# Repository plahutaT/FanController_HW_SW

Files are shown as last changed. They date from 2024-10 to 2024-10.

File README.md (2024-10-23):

# FanController PCB

A custom PCB for controlling fans in industrial electronic cabinets. It uses the PIC18F45K22 microcontroller and interfaces with two DS18B20 temperature sensors to regulate fan speed based on the temperature difference inside and outside the cabinet. It supports both 230V AC and 24V DC fans and has an option for logging data over TCP via an ESP01 module.

## Features

- Interfaces with two DS18B20 temperature sensors.
- Supports one 230V AC fan and one 24V DC fan.
- Regulates fan speed based on the temperature difference inside and outside the cabinet.
- Optional data logging over TCP using an ESP01 module.

## Hardware Components

- **Microcontroller**: PIC18F45K22
- **Temperature Sensors**: 2x DS18B20
- **Fan Support**:
  - 230V AC fan
  - 24V DC fan
- **Connectivity**: ESP01 module for optional data logging over TCP

### Prerequisites

- **MPLAB X IDE** for firmware development.
- **PICkit** or another compatible programmer for flashing the PIC18F45K22.
- PCB and components (refer to the Bill of Materials in the `/hardware` directory).

## Usage

Once powered on, the FanController PCB will:

- Read temperatures from the inside and outside DS18B20 sensors.
- Automatically adjust the speed of the connected 230V AC or 24V DC fan based on the temperature difference.
- Optionally, log temperature and fan speed data over TCP if the ESP01 module is connected and properly configured.

## License

This project is licensed under the MIT License. See the [LICENSE](LICENSE) file for details.

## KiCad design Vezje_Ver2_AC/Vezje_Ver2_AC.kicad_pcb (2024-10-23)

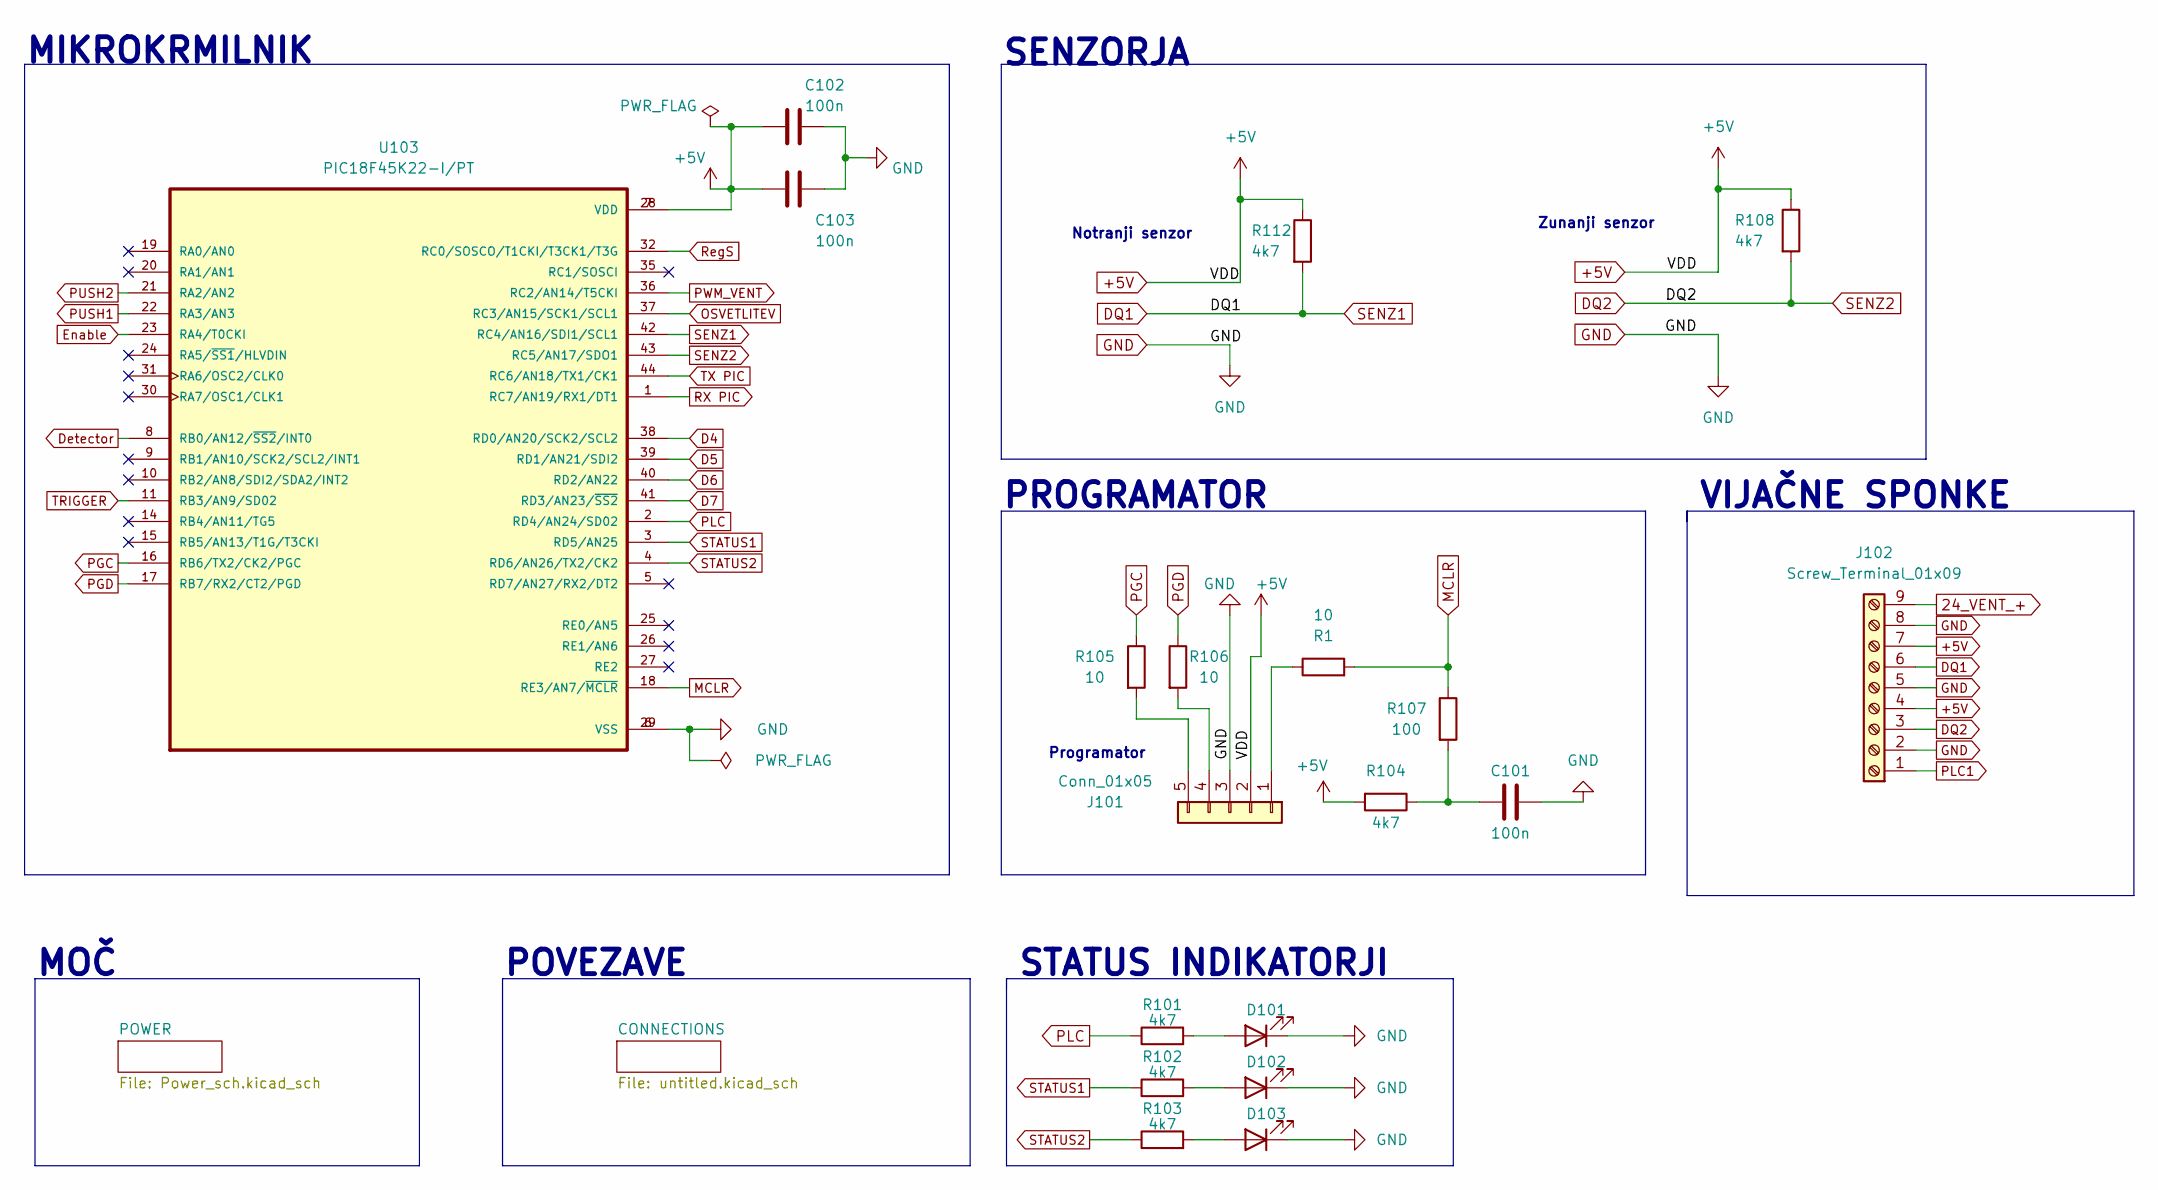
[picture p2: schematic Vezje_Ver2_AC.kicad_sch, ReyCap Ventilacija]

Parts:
C101, C102, C103: 100n; C_1206_3216Metric_Pad1.33x1.80mm_HandSolder
D101, D102, D103: LED; LED_1206_3216Metric_Pad1.42x1.75mm_HandSolder
J101: Conn_01x05; PinHeader_1x05_P2.54mm_Vertical
J102: Screw_Terminal_01x09; TerminalBlock_Phoenix_MKDS-1,5-9-5.08_1x09_P5.08mm_Horizont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
R1, R105, R106: 10; R_1206_3216Metric_Pad1.30x1.75mm_HandSolder
R101, R102, R103, R104, R108, R112: 4k7; R_1206_3216Metric_Pad1.30x1.75mm_HandSolder
R107: 100; R_1206_3216Metric_Pad1.30x1.75mm_HandSolder
U103: PIC18F45K22-I/PT; QFP80P1200X1200X120-44N

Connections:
24_VENT_+: J102.9; also elsewhere on the board
+5V: C102.1, C103.1, J101.2, J102.4, J102.7, R104.2, R108.1, R112.1, U103.7 (VDD), U103.28 (VDD); also elsewhere on the board
D4: U103.38 (RD0/AN20/SCK2/SCL2); also elsewhere on the board
D5: U103.39 (RD1/AN21/SDI2); also elsewhere on the board
D6: U103.40 (RD2/AN22); also elsewhere on the board
D7: U103.41 (RD3/AN23/~SS2); also elsewhere on the board
DQ1: J102.6, R112.2, U103.42 (RC4/AN16/SDI1/SCL1)
DQ2: J102.3, R108.2, U103.43 (RC5/AN17/SDO1)
Detector: U103.8 (RB0/AN12/~SS2/INT0); also elsewhere on the board
Enable: U103.23 (RA4/T0CKI); also elsewhere on the board
GND: C101.2, C102.2, C103.2, D101.1 (K), D102.1 (K), D103.1 (K), J101.3, J102.2, J102.5, J102.8, U103.6 (VSS), U103.29 (VSS); also elsewhere on the board
MCLR: R1.2, R107.1, U103.18 (RE3/AN7/~MCLR)
unnamed: C101.1, R104.1, R107.2
unnamed: D101.2 (A), R101.2
unnamed: D102.2 (A), R102.2
unnamed: D103.2 (A), R103.2
unnamed: J101.1, R1.1
unnamed: J101.4, R106.2
unnamed: J101.5, R105.2
OSVETLITEV: U103.37 (RC3/AN15/SCK1/SCL1); also elsewhere on the board
PGC: R105.1, U103.16 (RB6/TX2/CK2/PGC)
PGD: R106.1, U103.17 (RB7/RX2/CT2/PGD)
PLC: R101.1, U103.2 (RD4/AN24/SD02); also elsewhere on the board
PLC1: J102.1; also elsewhere on the board
PUSH1: U103.22 (RA3/AN3); also elsewhere on the board
PUSH2: U103.21 (RA2/AN2); also elsewhere on the board
PWM_VENT: U103.36 (RC2/AN14/T5CKI); also elsewhere on the board
RX PIC: U103.1 (RC7/AN19/RX1/DT1); also elsewhere on the board
RegS: U103.32 (RC0/SOSCO/T1CKI/T3CK1/T3G); also elsewhere on the board
STATUS1: R102.1, U103.3 (RD5/AN25)
STATUS2: R103.1, U103.4 (RD6/AN26/TX2/CK2)
TRIGGER: U103.11 (RB3/AN9/SD02); also elsewhere on the board
TX PIC: U103.44 (RC6/AN18/TX1/CK1); also elsewhere on the board

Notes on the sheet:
MOČ
Notranji senzor
VIJAČNE SPONKE
PROGRAMATOR
MIKROKRMILNIK
POVEZAVE
Programator
STATUS INDIKATORJI
SENZORJA
Zunanji senzor

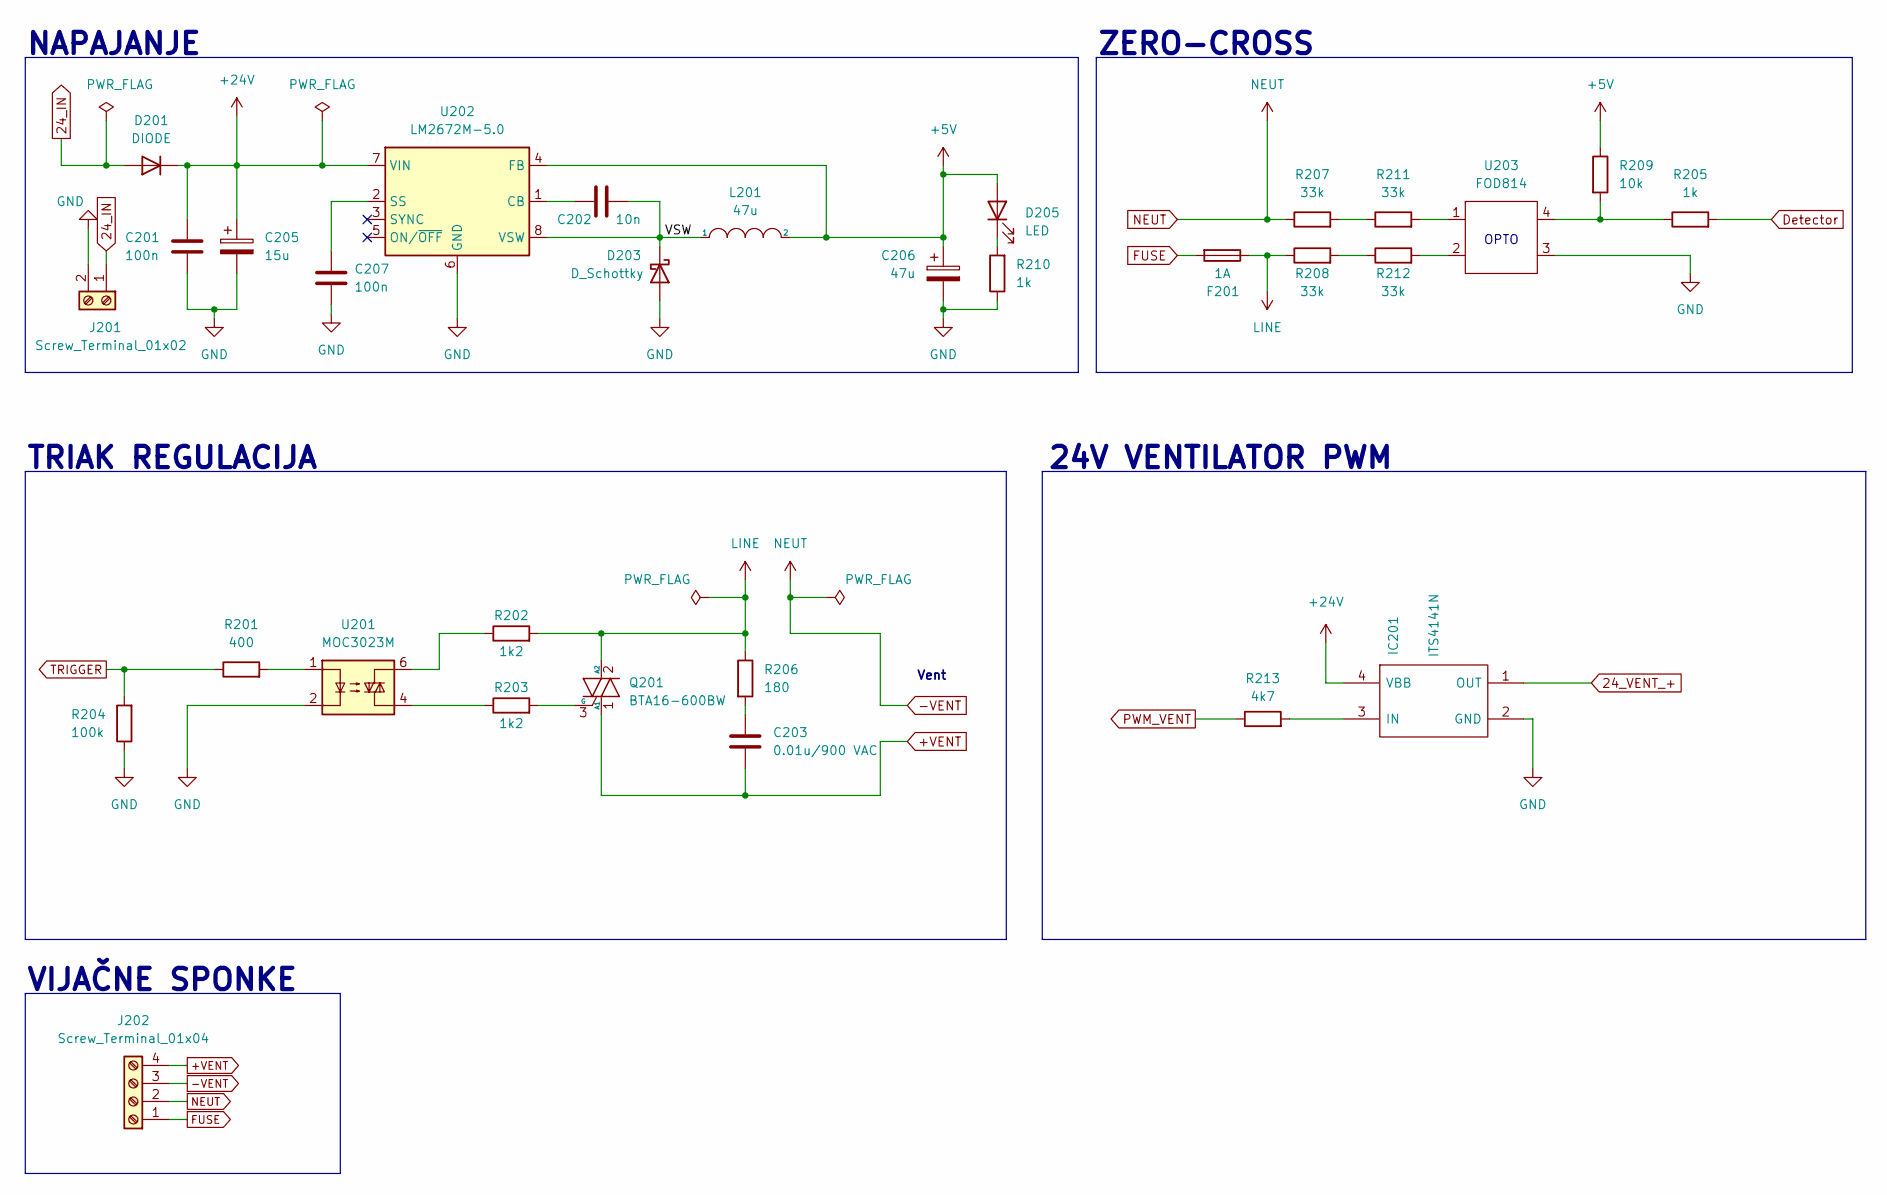
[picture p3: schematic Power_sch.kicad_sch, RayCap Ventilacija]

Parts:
C201, C207: 100n; C_1206_3216Metric_Pad1.33x1.80mm_HandSolder
C202: 10n; C_1206_3216Metric_Pad1.33x1.80mm_HandSolder
C203: 0.01u/900 VAC; C_Rect_L18.0mm_W5.0mm_P15.00mm_FKS3_FKP3
C205: 15u; CP_Elec_8x6.7
C206: 47u; CP_Elec_6.3x9.9
D201: DIODE; D_SMB
D203: D_Schottky; D_SMB
D205: LED; LED_1206_3216Metric_Pad1.42x1.75mm_HandSolder
F201: 1A; 696105003002
IC201: ITS4141N; SOT230P700X170-4N; Manufacturer_Part_Number ITS4141N; Mouser Part Number 726-ITS4141N
J201: Screw_Terminal_01x02; TerminalBlock_Phoenix_MKDS-1,5-2-5.08_1x02_P5.08mm_Horizont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
J202: Screw_Terminal_01x04; TerminalBlock_Phoenix_MKDS-1,5-4-5.08_1x04_P5.08mm_Horizont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
L201: 47u; L_7.3x7.3_H3.5
Q201: BTA16-600BW; TO-220-3_Vertical
R201: 400; R_1206_3216Metric_Pad1.30x1.75mm_HandSolder
R202, R203: 1k2; R_Axial_DIN0207_L6.3mm_D2.5mm_P10.16mm_Horizontal
R204: 100k; R_1206_3216Metric_Pad1.30x1.75mm_HandSolder
R205, R210: 1k; R_1206_3216Metric_Pad1.30x1.75mm_HandSolder
R206: 180; R_Axial_DIN0207_L6.3mm_D2.5mm_P10.16mm_Horizontal
R207, R208, R211, R212: 33k; R_1210_3225Metric_Pad1.30x2.65mm_HandSolder
R209: 10k; R_1206_3216Metric_Pad1.30x1.75mm_HandSolder
R213: 4k7; R_1206_3216Metric_Pad1.30x1.75mm_HandSolder
U201: MOC3023M; DIP-6_W7.62mm
U202: LM2672M-5.0; SOIC-8_3.9x4.9mm_P1.27mm
U203: FOD814; DIP762W50P254L510H440Q4

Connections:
24_IN: D201.2 (K), J201.1
24_VENT_+: IC201.1 (OUT); also elsewhere on the board
+5V: C206.1, D205.2 (A), L201.2, R209.1, U202.4 (FB); also elsewhere on the board
+24V: C201.1, C205.1, D201.1 (A), IC201.4 (VBB), U202.7 (VIN); also elsewhere on the board
+VENT: C203.2, J202.4, Q201.1 (A1)
-VENT: J202.2, J202.3, R207.1
/POWER/VSW: C202.2, D203.1 (K), L201.1, U202.8 (VSW)
Detector: R205.2; also elsewhere on the board
FUSE: F201.2, J202.1
GND: C201.2, C205.2, C206.2, C207.2, D203.2 (A), IC201.2 (GND), J201.2, R204.1, R210.1, U201.2, U202.6 (GND), U203.3; also elsewhere on the board
LINE: F201.1, Q201.2 (A2), R202.2, R206.1, R208.1
unnamed: C202.1, U202.1 (CB)
unnamed: C203.1, R206.2
unnamed: C207.1, U202.2 (SS)
unnamed: D205.1 (K), R210.2
unnamed: IC201.3 (IN), R213.2
unnamed: Q201.3 (G), R203.2
unnamed: R201.2, U201.1
unnamed: R202.1, U201.6
unnamed: R203.1, U201.4
unnamed: R205.1, R209.2, U203.4
unnamed: R207.2, R211.1
unnamed: R208.2, R212.1
unnamed: R211.2, U203.1
unnamed: R212.2, U203.2
PWM_VENT: R213.1; also elsewhere on the board
TRIGGER: R201.1, R204.2; also elsewhere on the board

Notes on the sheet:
24V VENTILATOR PWM
OPTO
NAPAJANJE
VIJAČNE SPONKE
Vent
ZERO-CROSS
TRIAK REGULACIJA

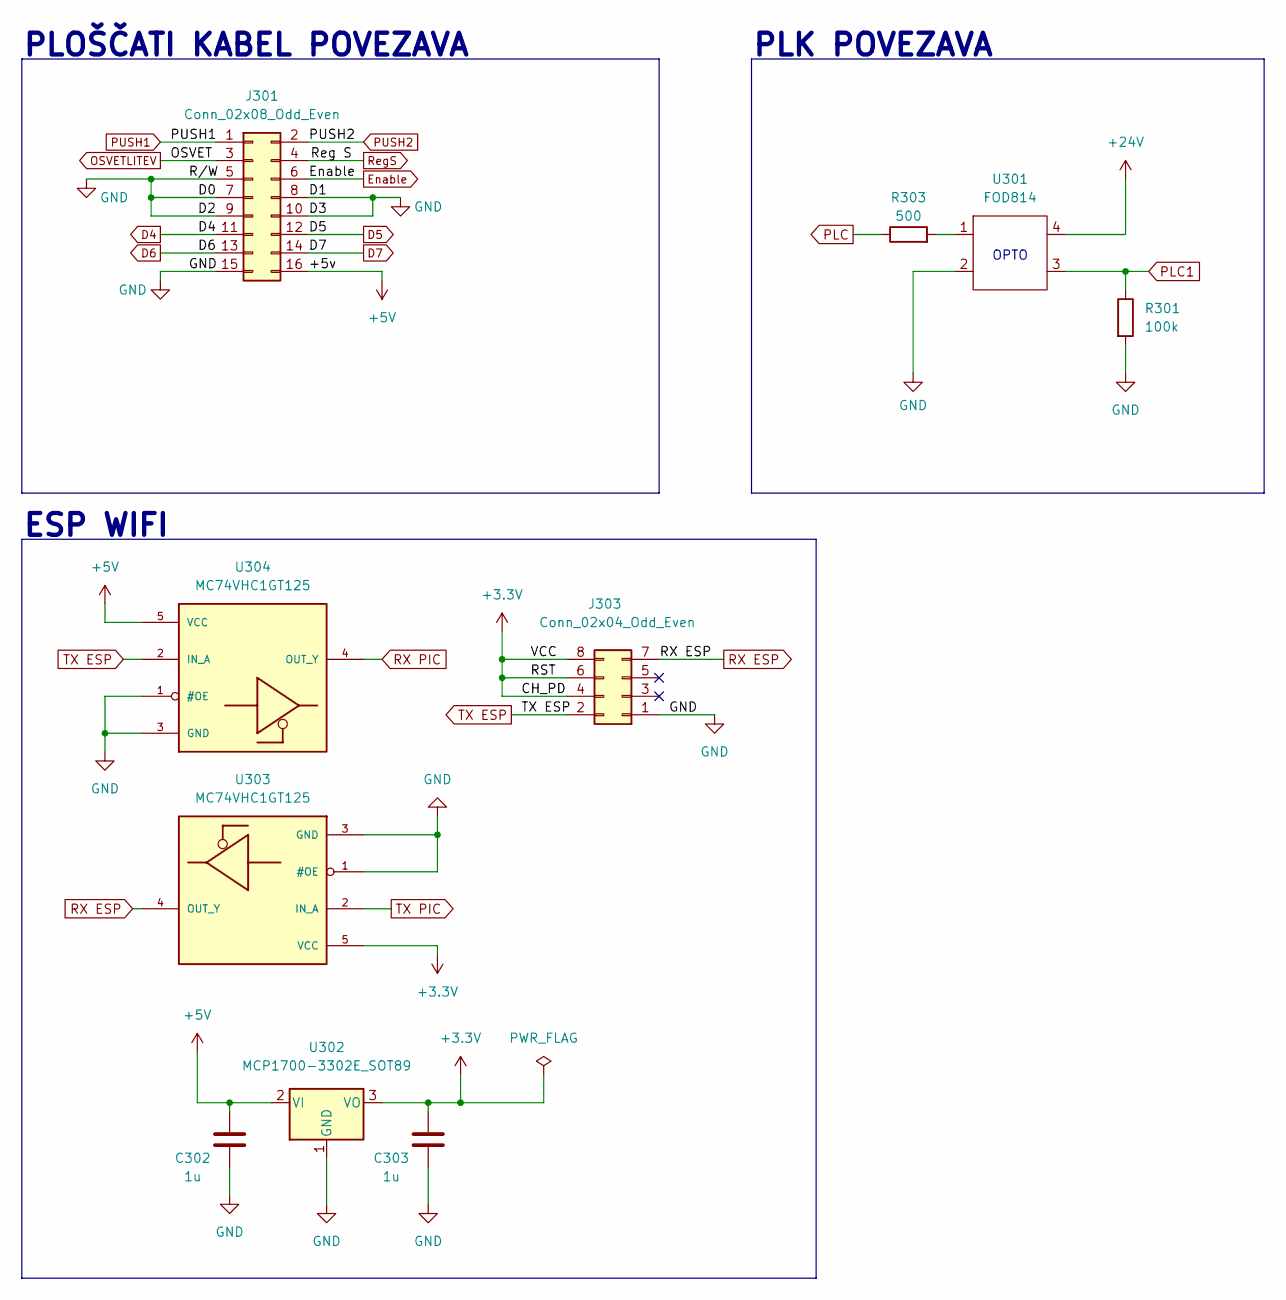
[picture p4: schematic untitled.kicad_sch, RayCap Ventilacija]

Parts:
C302, C303: 1u; C_1206_3216Metric_Pad1.33x1.80mm_HandSolder
J301: Conn_02x08_Odd_Even; PinSocket_2x08_P2.54mm_Vertical
J303: Conn_02x04_Odd_Even; PinSocket_2x04_P2.54mm_Vertical
R301: 100k; R_1206_3216Metric_Pad1.30x1.75mm_HandSolder
R303: 500; R_1206_3216Metric_Pad1.30x1.75mm_HandSolder
U301: FOD814; DIP762W50P254L510H440Q4
U302: MCP1700-3302E_SOT89; SOT-89-3_Handsoldering
U303, U304: MC74VHC1GT125; SOT23-5

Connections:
+3.3V: C303.2, J303.4, J303.6, J303.8, U302.3 (VO), U303.5 (VCC)
+5V: C302.2, J301.16, U302.2 (VI), U304.5 (VCC); also elsewhere on the board
+24V: U301.4; also elsewhere on the board
D4: J301.11; also elsewhere on the board
D5: J301.12; also elsewhere on the board
D6: J301.13; also elsewhere on the board
D7: J301.14; also elsewhere on the board
Enable: J301.6; also elsewhere on the board
GND: C302.1, C303.1, J301.5, J301.7, J301.8, J301.9, J301.10, J301.15, J303.1, R301.2, U301.2, U302.1 (GND), U303.1 (#OE), U303.3 (GND), U304.1 (#OE), U304.3 (GND); also elsewhere on the board
unnamed: R303.2, U301.1
OSVETLITEV: J301.3; also elsewhere on the board
PLC: R303.1; also elsewhere on the board
PLC1: R301.1, U301.3; also elsewhere on the board
PUSH1: J301.1; also elsewhere on the board
PUSH2: J301.2; also elsewhere on the board
RX ESP: J303.7, U303.4 (OUT_Y)
RX PIC: U304.4 (OUT_Y); also elsewhere on the board
RegS: J301.4; also elsewhere on the board
TX ESP: J303.2, U304.2 (IN_A)
TX PIC: U303.2 (IN_A); also elsewhere on the board

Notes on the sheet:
ESP WIFI
PLK POVEZAVA
OPTO
PLOŠČATI KABEL POVEZAVA

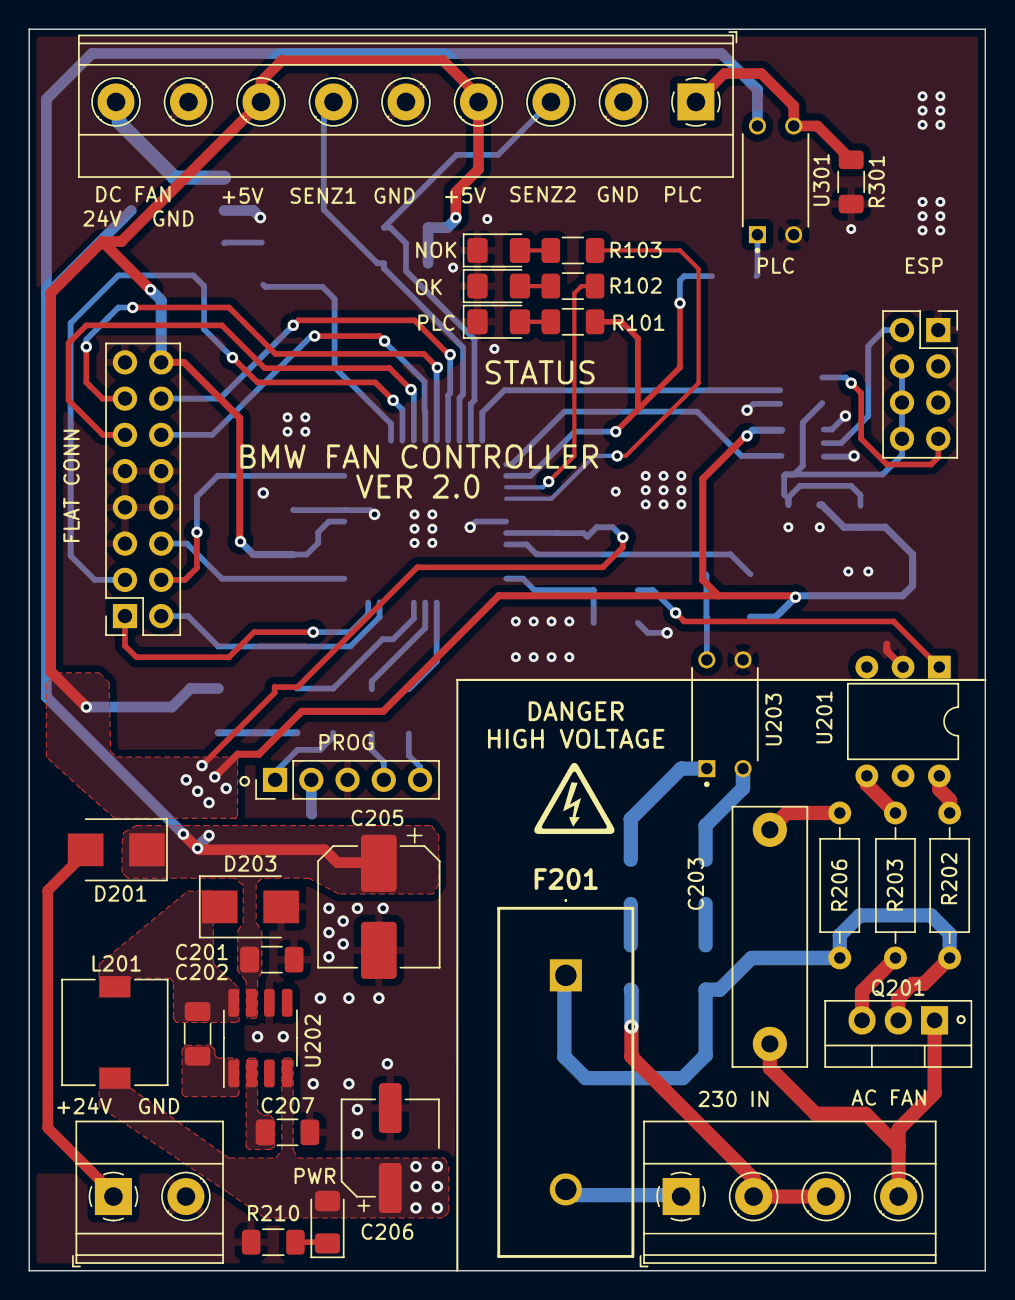
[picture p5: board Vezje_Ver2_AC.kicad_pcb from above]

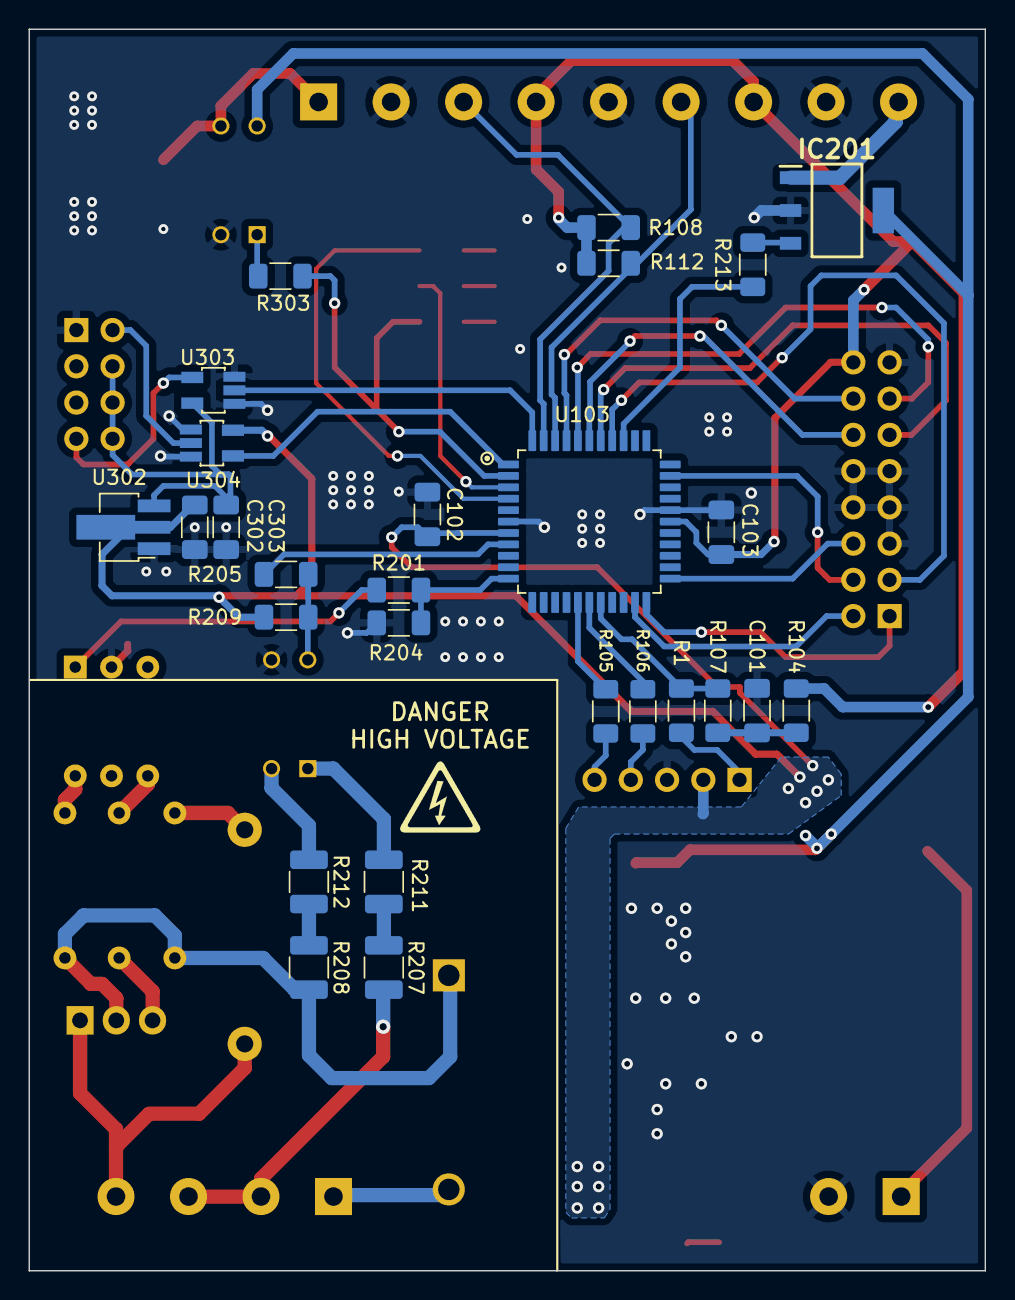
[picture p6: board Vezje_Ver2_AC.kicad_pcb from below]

Board: 2 copper layers, 67.0 x 87.0 mm, 60 parts (27 on the bottom side), 58 nets.

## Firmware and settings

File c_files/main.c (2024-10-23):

/*
 * File:   main.c
 * Author: tilen
 *
 * Created on March 8, 2023, 1:22 PM
 */

#include "config.h"
#include <xc.h>
#include "onewire.h"
#include "LCD.h"
#include <stdio.h>
#include <pic18f45k22.h>
#include "state_machine.h"
#include "button.h"
#include "eeprom.h"
#include "DC_fan_ctrl.h"


//#define DEBUG


#define _XTAL_FREQ 16000000
#define TRIGGER LATBbits.LATB3;
#define LED_OK LATDbits.LATD5;
#define LED_NOK LATDbits.LATD6;
#define OSVETLITEV LATCbits.LATC3;

volatile uint16_t count = 0;
volatile uint8_t debounce_count = 0;
volatile uint32_t multitaskTimer = 0;


//char buffer_g[10];
//char buffer2_g[10];
uint16_t Temp = 0;
uint16_t Temp2 = 0;
uint8_t Ref_temp = 20;
uint8_t Main_menu_F = 0;
uint8_t Main_menu2_F = 0;
uint8_t Filter_F = 0;
uint8_t DC_fan_F = 1;
uint8_t DC_fan_running_F = 0;


//float pogresek = 0;
uint8_t timer_3_fill_H = 0xC1;
uint8_t timer_3_fill_L = 0x80;

void InitTimer3();
void InitTimer5();
void Initialize(void);
void DisINT0(void);
void EnINT0(void);


#ifdef DEBUG

    /* Koda ki zelimo da se izvaja v debug verziji
     * Timer dela interrut na 10ms, tako simuliramo AC interrupt
     * 
     *   */

    void __interrupt(low_priority) LowIsr(void){

         if (PIR1bits.TMR1IF && PIE1bits.TMR1IE){
            PIR1bits.TMR1IF = 0;
            count++;
            debounce_count++;
            multitaskTimer++;

            //LATBbits.LATB3 = 1;    // prizgemo triac
         }
    }
    

#endif


#ifndef DEBUG

    void __interrupt(low_priority) LowIsr(void){

       
            
        if (PIR2bits.TMR3IF && PIE2bits.TMR3IE) {
            PIR2bits.TMR3IF = 0;   // clear Timer3 flag
            LATBbits.LATB3 = 1;    // trigger TRIAC
        }
      
        
        if (PIR5bits.TMR5IF && PIE5bits.TMR5IE) {
            PIR5bits.TMR5IF = 0;   // clear Timer3 flag
            count++;
            debounce_count++;
            multitaskTimer++;   
        }
         
       
    }



    void __interrupt(high_priority) HighIsr(void){

        /* Interrupt funkcija preverja kateri Interrupt e je zgodil
            RB0 Interrupt prozi na 10ms v ISR je treba ugasnit triac in napolnit timer ki bo nato prozil triac
        */

        if(INTCONbits.INT0IF && INTCONbits.INT0IE){

            INTCONbits.GIEH = 0;     // Prekini vse prekinitve
            LATBbits.LATB3 = 0;    // ugasnemo triac
            count++;
            debounce_count++;
            multitaskTimer++;

            // loadamo timer z pravilnimi vrednostmi za zeleno zakasnitev
            TMR3H = timer_3_fill_H;
            TMR3L = timer_3_fill_L;

            //PIE1bits.TMR1IE = 1;           // enejblas interrupt ce ni Fullspeed_F setan
            PIR2bits.TMR3IF = 0;
            INTCONbits.INT0IF = 0;           // clearas interrupt flag bit
            INTCONbits.GIEH = 1;              // Vklop prekinitev

        }
       
        

        /*
        if(Fullspeed_F){
            PIE1bits.TMR1IE = 0;
            LATBbits.LATB3 = 1; //prizgi triak
        }
        */
        
    }

#endif




void main(void) {
    
    /*  Initializations    */
 
    Initialize();
    InitTimer3();
    InitTimer5();
    PWM_Init();
    
    /* Preberi vrednost reference iz EEPROM  */
	//Ref_temp = read_internal_eeprom(0x60);
    
    
    LATCbits.LATC3 = 0;
    __delay_ms(300);
    LCD_init();
    __delay_ms(100);
    LCD_clear();
    
    __delay_ms(300);      // delay da se stabilizira ekran
    
    //UART_init();
    //UART_115200_baud();
    LATBbits.LATB3 = 0;    // ugasnemo triac
    
    __delay_ms(500);
    
    /*  State machine init   */
    
    state_codes cur_state = temp_measure_inside; //testiraj ce deluje isto z temp_measure_inside // ustvarimo trenutni state         
    ret_codes rc;                                 // ustvarimo variable ki hrani return vrednosti fnkcij statov
    uint8_t (* state_func)(void);                 // ustvarimo pointer na funkcije statov
    
    
    
    /*   Variables    */
    uint8_t both_pressed = 0;
    uint32_t Wifi_ticks = 0;
    
    while(1){
        
        /*   Logika za laufanje state machina   */
        
        state_func = state_funcs[cur_state];
        rc = state_func();    
        cur_state = lookup_transitions(cur_state, rc);
        
        
        /*   Button check  
         *   checkiramo ali so pritisnjena oba gumba 
         *   ce so gremo v main menu
         */
        
        /*
        LCD_cursor_set(1, 1);
        LCD_write_string("TEST");
        LCD_cursor_set(2, 1);
        LCD_write_string("24DC");
        */
        
        
        
        both_pressed = Both_Button_Pressed();
        
        if(both_pressed){
            LCD_clear();
            Main_menu_F = 1;
            
            cur_state = main_menu;    //nastavimo state na main menu
        }
        
        /* Treba je naredit da gre v wifi state usakih par min   */
        
        // Trenutno nerabimo WIFI state
        /*
        if(multitaskTimer - Wifi_ticks >= 30000){        // 6000 je ena minuta
            //TODO nastavi state da je wifi
            cur_state = wifi_send_temp;
            Wifi_ticks = multitaskTimer;
        }
        */
        
        
        
        
        
        
        __delay_ms(200);
        
    }
    
    
    /* Fail safe loop  */
    while(1){}
    
    return;
}

void Initialize(void){
    
    OSCCON = 0B01110010;
    ANSELB = 0x00;
    ANSELD = 0x00;
    ANSELC = 0x00;
    ANSELE = 0x00;
    ANSELA = 0x00;
    TRISD = 0b00000000;
    TRISC = 0b00000000;
    TRISA = 0b00001111;
    TRISE = 0b00001111;
    TRISB = 0b00000001;           // nastavimo B0 na input
   


    CM1CONbits.C1ON = 0;            // Disable comparators
    CM2CONbits.C2ON = 0;
     
    ADCON0 = 0x00;              // ugasnemo ADC
    
    
    INTCONbits.INT0IE = 0;      // na zacetku disejblamo interupt na RB0 ki je INT0
    INTCON2bits.INTEDG0 = 1;    // interupt INT0 prozi na rising edge
    INTCONbits.INT0IE = 1;    // enejblamo interupt na RB0
    
    RCONbits.IPEN = 1;          // enable priority
    INTCONbits.PEIE_GIEL = 1;           // enejbelamo peripheral high priority intrrupts
    INTCONbits.GIE_GIEH = 1;         // enejblamo global interupts
    
}

void InitTimer3(){
    T3CON         = 0x01;
    IPR2bits.TMR3IP = 0;      // low priority
    PIR2bits.TMR3IF = 0;
    TMR3H         = 0x63;     // 0x63, 0xC0 je za 10ms
    TMR3L         = 0xC0;
    PIE2bits.TMR3IE = 1;
    //INTCON         = 0xC0;          // to je jebalo sistem
}

void InitTimer5(){
  T5CON	 = 0x01;
  IPR5bits.TMR5IP = 0;  
  PIR5bits.TMR5IF = 0;
  TMR5H	 = 0x63;
  TMR5L	 = 0xC0;
  PIE5bits.TMR5IE = 1;
  //INTCON	 = 0xC0;
}

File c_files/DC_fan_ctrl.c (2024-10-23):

#include <pic18f45k22.h>
#include "DC_fan_ctrl.h"





void PWM_Init(void) {
    // Set the RC2 pin as output
    TRISCbits.RC2 = 0;

    // Set up ECCP1 module in PWM mode
    CCP1CONbits.P1M = 0;        // Single output mode
    CCP1CONbits.CCP1M = 0b1100; // PWM mode

    // Set the PWM frequency (Period)
    // PR2 = [(_XTAL_FREQ / (PWM_freq * TMR2_prescale * 4)) - 1]
    // Example: PWM frequency = 5kHz, prescaler = 16
    PR2 = 249; // for 5kHz PWM with 16 prescaler

    // Set initial duty cycle (50% example)
    // Initial duty cycle to 50% (512/1023)
    PWM_SetDutyCycle(818);

    // Configure Timer2 for PWM
    T2CONbits.T2CKPS = 0b10;     // Timer2 prescaler 16
    T2CONbits.TMR2ON = 1;        // Turn on Timer2

    // Wait until Timer2 is ready
    while (!PIR1bits.TMR2IF);
    PIR1bits.TMR2IF = 0;
}

void PWM_SetDutyCycle(uint16_t duty_cycle) {
    // duty_cycle is a value between 0 and 1023 (10-bit)
    if (duty_cycle > 1023) {
        duty_cycle = 1023; // Cap duty cycle to 1023 (100%)
    }

    // Set the duty cycle (10-bit value)
    CCPR1L = duty_cycle >> 2;         // Upper 8 bits
    CCP1CONbits.DC1B = duty_cycle & 0x03;  // Lower 2 bits
}
